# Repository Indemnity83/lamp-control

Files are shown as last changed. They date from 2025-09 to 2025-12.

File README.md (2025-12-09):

# ESPHome Reading Lamp (Lamp Control)

This project is a custom **ESP8266 (ESP-12E) + ESPHome retrofit** for a standard touch‑controlled bedside reading lamp, adding full **Wi‑Fi control and Home Assistant integration**.

Originally built for a fun (and slightly devious) bedtime automation, it’s now a clean, reusable **smart‑lamp controller** with both **open hardware** and **open firmware**.

Same lamp on the outside.  
Entirely new personality on the inside.

---

## ✨ Features

- ESP8266 / ESP‑12E based Wi‑Fi control  
- ESPHome firmware  
- Home Assistant native API integration  
- Smooth transitions and dimming  
- Designed to replace a stock capacitive touch controller  
- Brightness memory across power loss  
- Physical touch control + full network control

---

## 🗂️ Repository Structure

- `firmware/` – ESPHome configuration and device logic  
- `hardware/` – KiCad schematic, PCB, and mechanical assets  
- `docs/` – Rendered schematic and board images

---

## 🧠 Hardware Overview

The controller is built around a simple, low‑voltage architecture composed of four primary building blocks:

1. **Micro — ESP8266 Wi‑Fi Module (ESP‑12E)**  
   Provides all network connectivity, ESPHome firmware execution, and integration with Home Assistant.

2. **Mosfet — BSS138 MOSFET‑Based DC Dimmer Stage**  
   Handles low‑side PWM dimming of the 12V lamp load in a safe, fully low‑voltage design (no mains switching).

3. **Power — AMS1117‑3.3 Linear Voltage Regulator**  
   Steps the incoming 12V DC down to a stable 3.3V rail for the ESP8266 and logic circuitry.

4. **Touch — TTP223 Capacitive Touch Sensor**  
   Provides the physical touch interface for on/off control and brightness stepping without any mechanical switches.

### Schematic

Schematic

### PCB Render

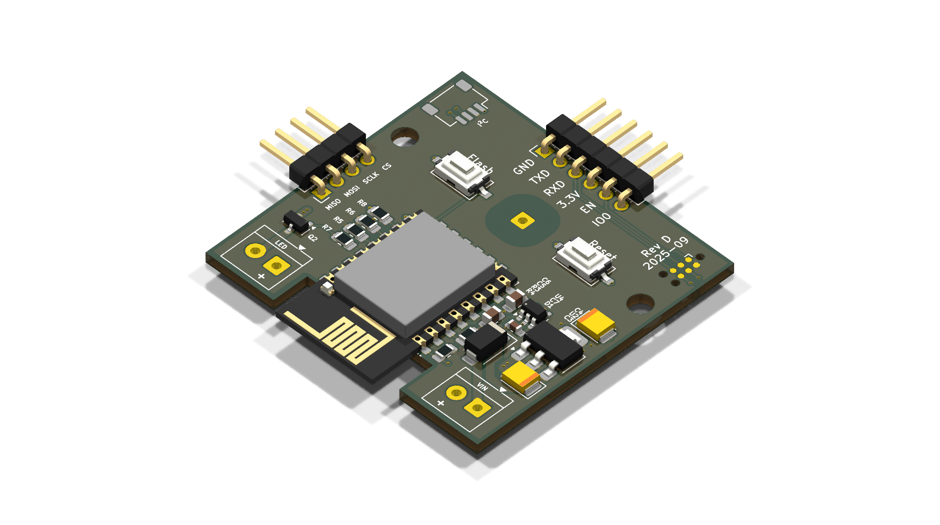
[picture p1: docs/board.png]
PCB Render


---

## 🏭 Manufacturing Assets

All fabrication outputs are generated from KiCad using the supplied Makefile:

```sh
make build
```

This generates, into the `hardware/build/` directory:

- Gerber files  
- Drill files  
- BOM (CSV)  
- Pick‑and‑place  
- PDF schematic

Manufacturing assets are also published as **GitHub Releases** and workflow artifacts.

### 🟣 Order a Pre‑Fab PCB (OSH Park)

If you prefer to skip fabrication setup and order the board directly, the exact PCB is available as a shared OSH Park project:

https://oshpark.com/shared_projects/FYbiIZpP

---

## 🧰 Bill of Materials (BOM) — Summary

This project retrofits a **touch‑controlled 12V DC bedside reading lamp** with a custom ESP8266 controller.

### 🪔 Base Lamp

- Touch‑control bedside reading lamp (original retail unit)  
- Any similar **12V capacitive‑touch lamp with an internal controller** can be adapted; however, the **PCB outline and mounting points are specifically designed for [this exact lamp model](https://a.co/d/2ksPzuO)**

> ⚠️ **USB Charging Port Note**  
> The original lamp’s built-in USB charging port will be **non-functional after this retrofit**. Supporting a protected 5V USB output (with proper current limiting and fault protection) was intentionally left **out of scope** to keep the board simple and safe.  
>  
> If you would like to restore USB charging, the recommended approach is to use a small, dedicated **12V → 5V buck converter module** and reuse the lamp’s original USB connector:  
> 1. Install a 12V → 5V buck converter module and connect the lamp’s 12V supply to the module’s input.  
> 2. **Remove the USB connector from the buck converter module** so you can access its 5V and GND output pads directly.  
> 3. Solder the original USB wiring to the 5V and GND output pads on the buck converter module, effectively feeding the original USB jack from the new 5V supply.  
>  
> Example module: https://a.co/d/jlBtOT4

> ♻️ **Salvage & Reuse Note**  
> The **spring contact** that connects the original lamp PCB to the outer plastic touch surface is **re‑used in this design**. Be sure to **pull and transfer this spring from the original board** when installing the new controller.
> 
> You can also optionally **salvage the following components from the original lamp PCB** to reduce parts sourcing:
> - The **MOSFET** (dimmer switch)
> - The tiny **22pF capacitor** used to decouple the touch spring
> - **Reverse‑polarity protection diode** (SS14‑class)
> 
> Salvaging these parts is optional but can simplify sourcing and keep e‑waste down.

### 🧠 Core Electronics

- **U3 — ESP‑12E / ESP8266 Wi‑Fi module**
- **U4 — TTP223‑BA6 capacitive touch sensor**
- **Q2 — BSS138 MOSFET** (low‑side PWM dimming)
- **U2 — AMS1117‑3.3 voltage regulator**
- **D1 — SS14 Schottky diode** (power protection)
- Decoupling and timing capacitors (C3–C7)
- Pull‑ups and current‑limit resistors (R3–R8)

---

## 🧑‍💻 Firmware

The device firmware is written in **ESPHome** and provides:

- Touch input handling via TTP223B capacitive IC  
- Brightness stepping with persistent memory  
- Long‑press physical power‑off  
- OTA updates and Home Assistant API integration

Firmware configuration files live in:

```
firmware/
```

---

## ⚡ Typical Use Cases

- Smart bedside reading lamps  
- Bedtime automations  
- Wake‑up fade lighting  
- General ESPHome‑controlled lighting

---

## 📄 License

This project uses **dual licensing**:

- **Firmware & configuration:** MIT License  
- **Hardware designs & mechanical files:** CERN Open Hardware License v2 – Permissive (CERN‑OHL‑P)

See the respective `LICENSE.md` files for full terms.

---

## ❤️ Why This Exists

Because sometimes the right solution to:

> “They’re still reading at 10 PM…”

is:

> “Fine. We’ll let the robots handle it.”

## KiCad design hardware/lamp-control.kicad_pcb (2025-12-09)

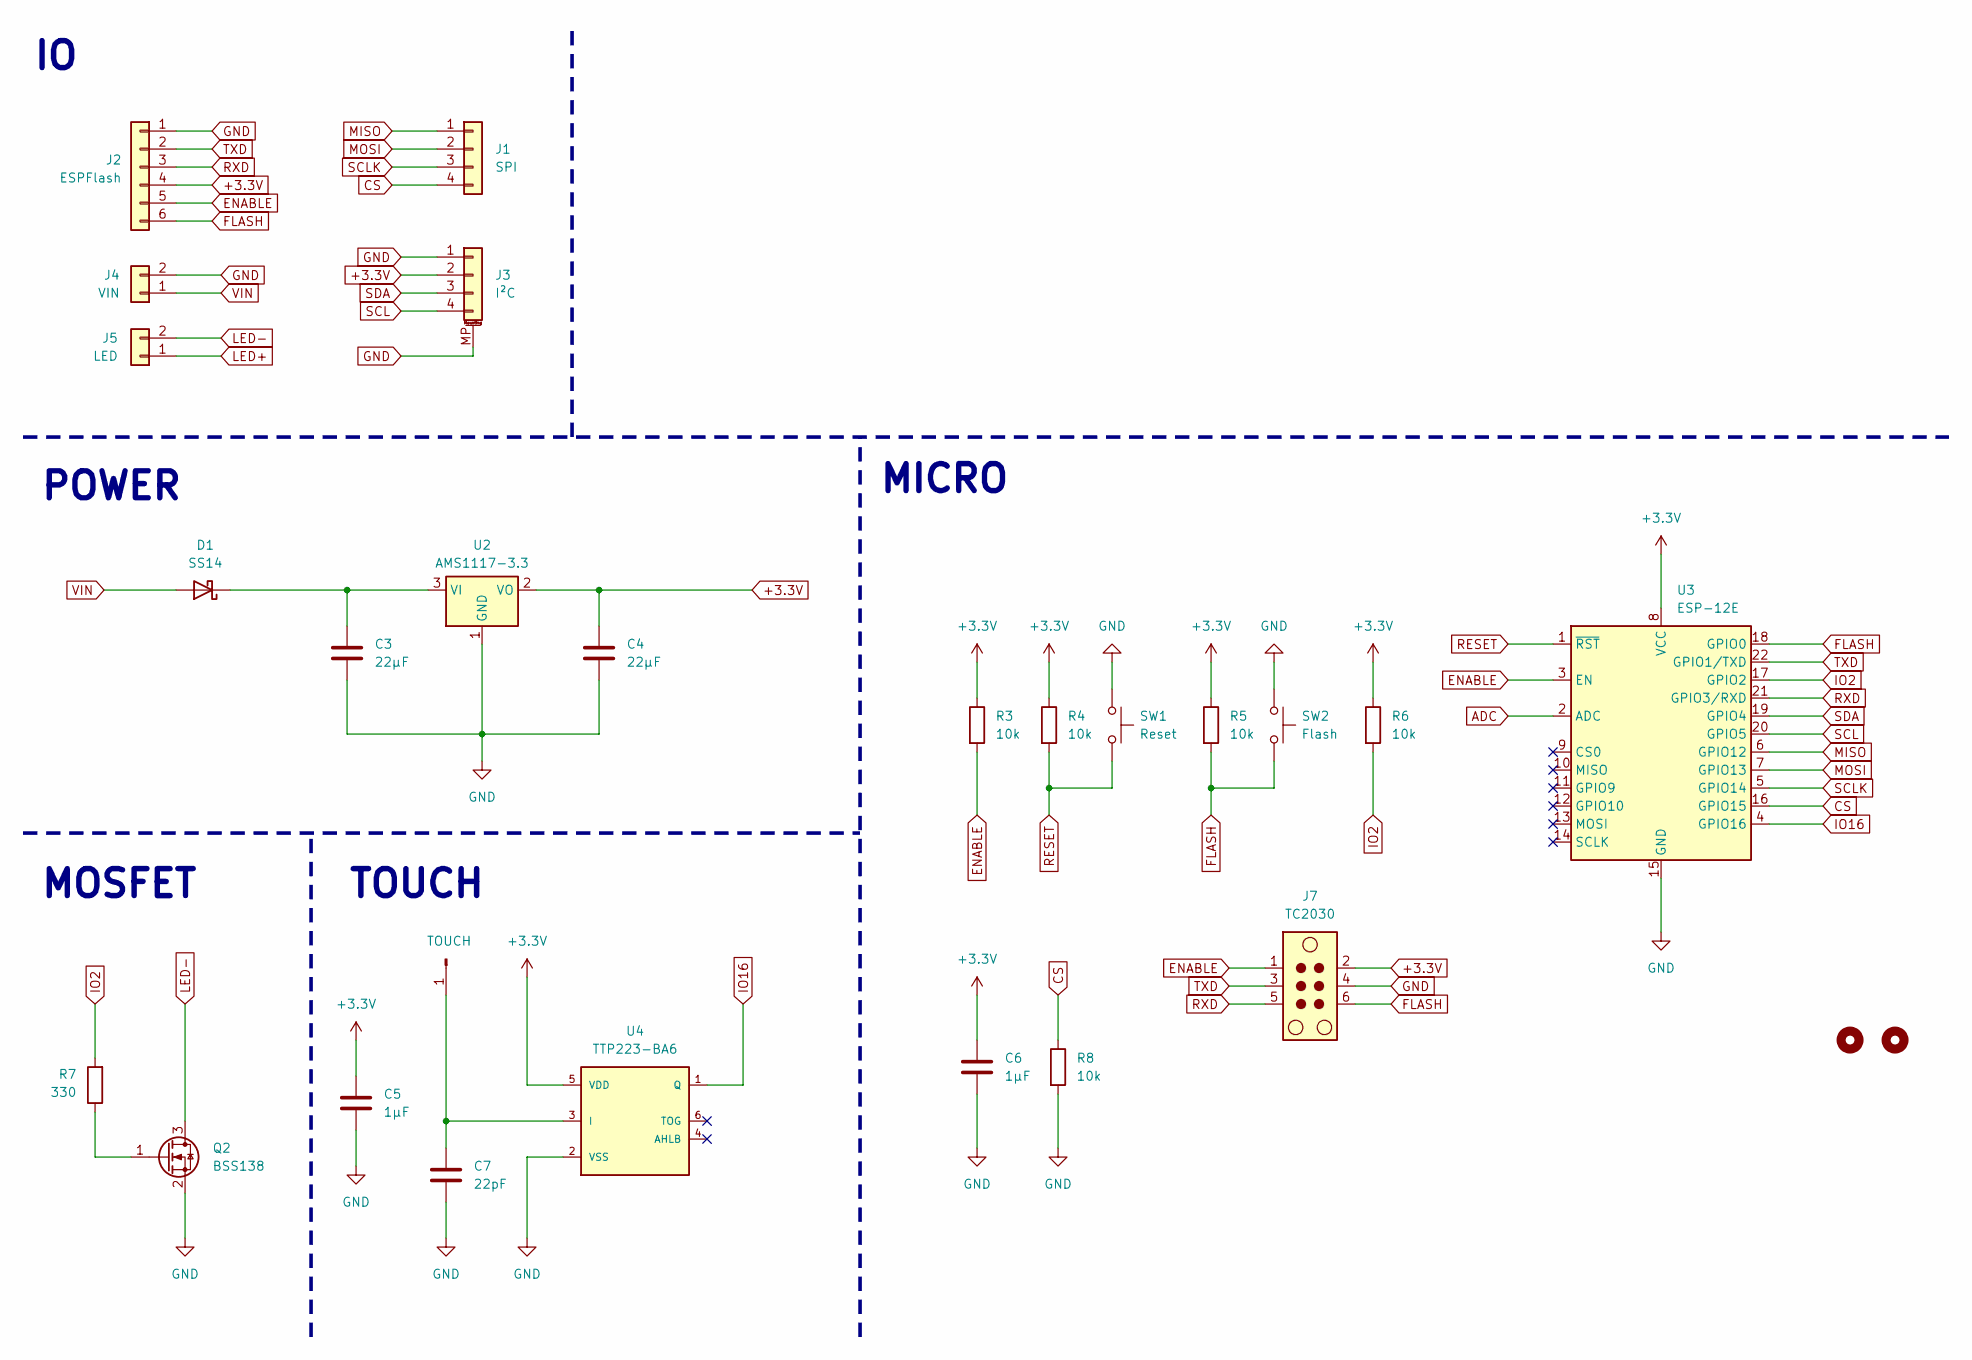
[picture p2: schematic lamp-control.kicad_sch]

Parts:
C3, C4: 22µF; CP_EIA-3528-12_Kemet-T_HandSolder
C5, C6: 1µF; C_0805_2012Metric_Pad1.18x1.45mm_HandSolder
C7: 22pF; C_0603_1608Metric_Pad1.08x0.95mm_HandSolder
D1: SS14; D_SMA
H1, H2: MountingHole; MountingHole_3.2mm_M3
J1: SPI; PinHeader_1x04_P2.54mm_Horizontal
J2: ESPFlash; PinHeader_1x06_P2.54mm_Horizontal
J3: I²C; JST_SH_SM04B-SRSS-TB_1x04-1MP_P1.00mm_Horizontal
J4: VIN; TerminalBlock_4Ucon_1x02_P3.50mm_Horizontal
J5: LED; TerminalBlock_4Ucon_1x02_P3.50mm_Horizontal
J6: TOUCH; SolderWire-0.5sqmm_1x01_D0.9mm_OD2.1mm
J7: TC2030; Tag-Connect_TC2030-IDC-NL_2x03_P1.27mm_Vertical
Q2: BSS138; SOT-23
R3, R4, R5, R6, R8: 10k; R_0805_2012Metric_Pad1.20x1.40mm_HandSolder
R7: 330; R_0805_2012Metric_Pad1.20x1.40mm_HandSolder
SW1: Reset; SW_Tactile_SPST_NO_Straight_CK_PTS636Sx25SMTRLFS
SW2: Flash; SW_Tactile_SPST_NO_Straight_CK_PTS636Sx25SMTRLFS
U2: AMS1117-3.3; SOT-223-3_TabPin2
U3: ESP-12E
U4: TTP223-BA6; SOT-23-6

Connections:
+3.3V: C4.1, C5.1, C6.1, J2.4, J3.2, J7.2, R3.1, R4.1, R5.1, R6.1, U2.2 (VO), U3.8 (VCC), U4.5 (VDD)
ADC: U3.2 (ADC)
CS: J1.4, R8.1, U3.16 (GPIO15)
ENABLE: J2.5, J7.1, R3.2, U3.3 (EN)
FLASH: J2.6, J7.6, R5.2, SW2.2, U3.18 (GPIO0)
GND: C3.2, C4.2, C5.2, C6.2, C7.1, J2.1, J3.1, J3.MP (MountPin), J4.2, J7.4, Q2.2 (S), R8.2, SW1.1, SW2.1, U2.1 (GND), U3.15 (GND), U4.2 (VSS)
IO2: R6.2, R7.2, U3.17 (GPIO2)
IO16: U3.4 (GPIO16), U4.1 (Q)
LED+: J5.1
LED-: J5.2, Q2.3 (D)
MISO: J1.1, U3.6 (GPIO12)
MOSI: J1.2, U3.7 (GPIO13)
unnamed: C3.1, D1.1 (K), U2.3 (VI)
unnamed: C7.2, J6.1, U4.3 (I)
unnamed: Q2.1 (G), R7.1
RESET: R4.2, SW1.2, U3.1 (~RST)
RXD: J2.3, J7.5, U3.21 (GPIO3/RXD)
SCL: J3.4, U3.20 (GPIO5)
SCLK: J1.3, U3.5 (GPIO14)
SDA: J3.3, U3.19 (GPIO4)
TXD: J2.2, J7.3, U3.22 (GPIO1/TXD)
VIN: D1.2 (A), J4.1

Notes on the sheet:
MICRO
TOUCH
POWER
MOSFET

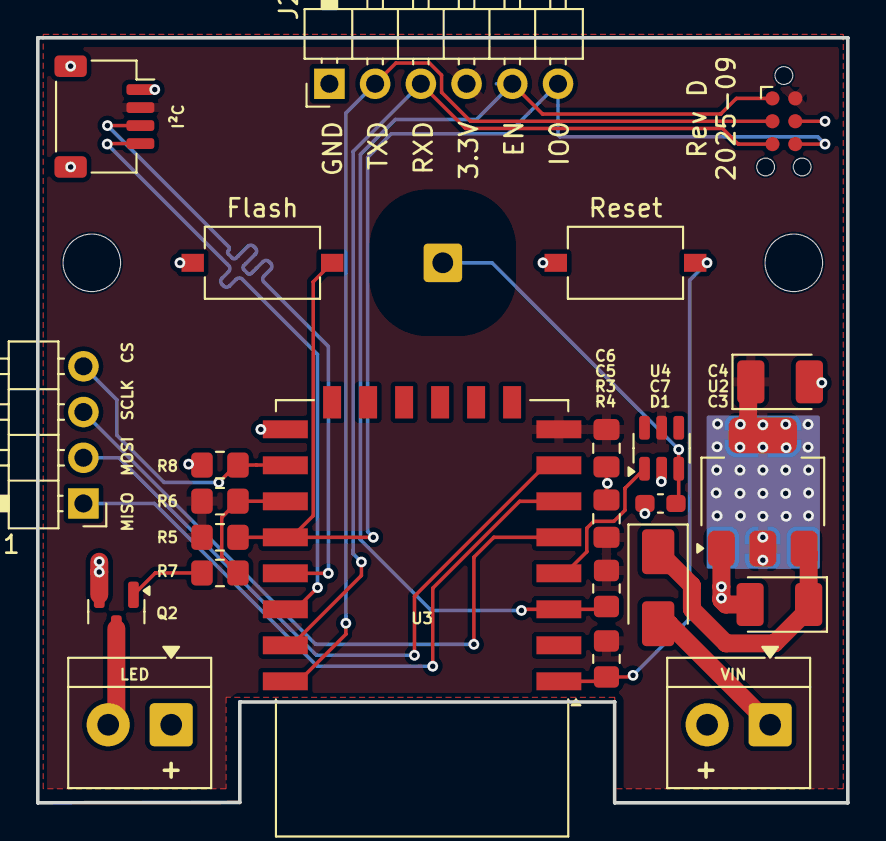
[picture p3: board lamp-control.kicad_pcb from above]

Board: 2 copper layers, 45.0 x 42.5 mm, 27 parts (0 on the bottom side), 20 nets.

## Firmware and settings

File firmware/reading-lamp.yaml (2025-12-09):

esphome:
  name: reading-lamp
  friendly_name: Reading Lamp

substitutions:
  ap_ssid: "${name}-setup"

esp8266:
  board: esp12e

# Enable logging over UART
logger:

# Enable Home Assistant native API
api:
  encryption:
    key: !secret encryption_key

# Enable OTA updates via ESPHome
ota:
  - platform: esphome
    password: !secret ota_password

wifi:
  ssid: !secret wifi_ssid
  password: !secret wifi_password

  # Fallback hotspot (captive portal) if Wi-Fi connection fails.
  # SSID/password are kept in secrets for privacy.
  ap:
    ssid: "${ap_ssid}"
    password: !secret reading_lamp_ap_password

captive_portal:

# Use Home Assistant as the time source (if ever needed for automations)
time:
  - platform: homeassistant
    id: ha_time

# Lightweight web UI for debugging / manual control
web_server:
  port: 80

# I2C bus (reserved for future use / sensors)
i2c:
  sda: GPIO4
  scl: GPIO5
  scan: true

globals:
  # Brightness step index (0–3).
  # This value IS restored across reboots (restore_value: yes), so the lamp
  # will return to the last-used brightness level even after power loss or restart.
  - id: brightness_step
    type: uint8_t
    restore_value: yes
    initial_value: '0'
    
output:
  # PWM output to drive the lamp (low-voltage side of the dimmer / LED driver).
  - platform: esp8266_pwm
    pin: GPIO02
    id: lamp_pwm
    frequency: 1000 Hz

light:
  - platform: monochromatic
    id: lamp_light
    name: "Reading Lamp"
    output: lamp_pwm
    default_transition_length: 300ms
    restore_mode: ALWAYS_OFF   # Always start off after power-up / reboot
    gamma_correct: 2.2         # More natural brightness curve

    # NOTE: We intentionally do NOT reset brightness_step here.
    # Design intent: when the lamp is turned off (via touch or HA),
    # turning it back on returns to the last used brightness level.

binary_sensor:
  - platform: gpio
    pin:
      number: GPIO16
      mode: INPUT
      inverted: false
    internal: true
    id: touch_sensor

    # Using a TTP223B touch IC on this pin, which already handles
    # debouncing and provides a clean digital signal.
    # No additional ESPHome filters are needed here.

    # Short click: turn on (if off) or cycle brightness levels (if on).
    on_click:
      then:
        - lambda: |-
            // If the lamp is currently on, advance to the next brightness step.
            // If it's off, keep the current step so the lamp turns back on
            // at the same brightness it was last used.
            if (id(lamp_light).current_values.is_on()) {
              id(brightness_step) = (id(brightness_step) + 1) % 4;
            }

            // Brightness levels: 100%, 75%, 50%, 25%.
            static const float L[4] = {1.0f, 0.75f, 0.50f, 0.25f};

            auto call = id(lamp_light).turn_on();
            call.set_brightness(L[id(brightness_step)]);
            call.perform();

    # Long press (hold ≥ 1s): turn the lamp off.
    # This is the only physical way to turn it off at the lamp itself,
    # so we keep this behavior simple and reliable.
    on_multi_click:
      - timing:
          - ON for at least 1s
        then:
          - light.turn_off: lamp_light

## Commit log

2025-09-03 Rev D
    [Lamp Circuit.kicad_pcb, Lamp Circuit.kicad_sch]
2025-09-07 Simplify design (#1)
    [Lamp Circuit.kicad_pcb, lamp-control.kicad_pcb, lamp-control.kicad_sch]
2025-09-07 install full kicad on build
2025-12-09 Update design files
    [lamp-control.kicad_pcb, lamp-control.kicad_sch]
2025-12-09 Speed up build workflow by caching KiCad APT packages
